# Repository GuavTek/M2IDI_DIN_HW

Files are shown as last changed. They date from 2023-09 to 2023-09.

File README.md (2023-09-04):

This eurorack module is a gateway between MIDI 1.0 over a 5-pin DIN cable, and MIDI 2.0 over the internal bus.
View this project on [CADLAB.io](https://cadlab.io/project/25234) to see renders of schematics and PCBs, as well as current issues. 

<h2> A part of the M2IDI prototypes </h2>

<p>
The code for this module can be found on  
<a href="https://github.com/GuavTek/M2IDI_DIN">
			  GitHub
		  </a>
</p>

<p> 
More info on the M2IDI system can be found on the 
<a href="https://hackaday.io/project/182092-modular-midi">
			  Hackaday project page
		  </a>

</p>

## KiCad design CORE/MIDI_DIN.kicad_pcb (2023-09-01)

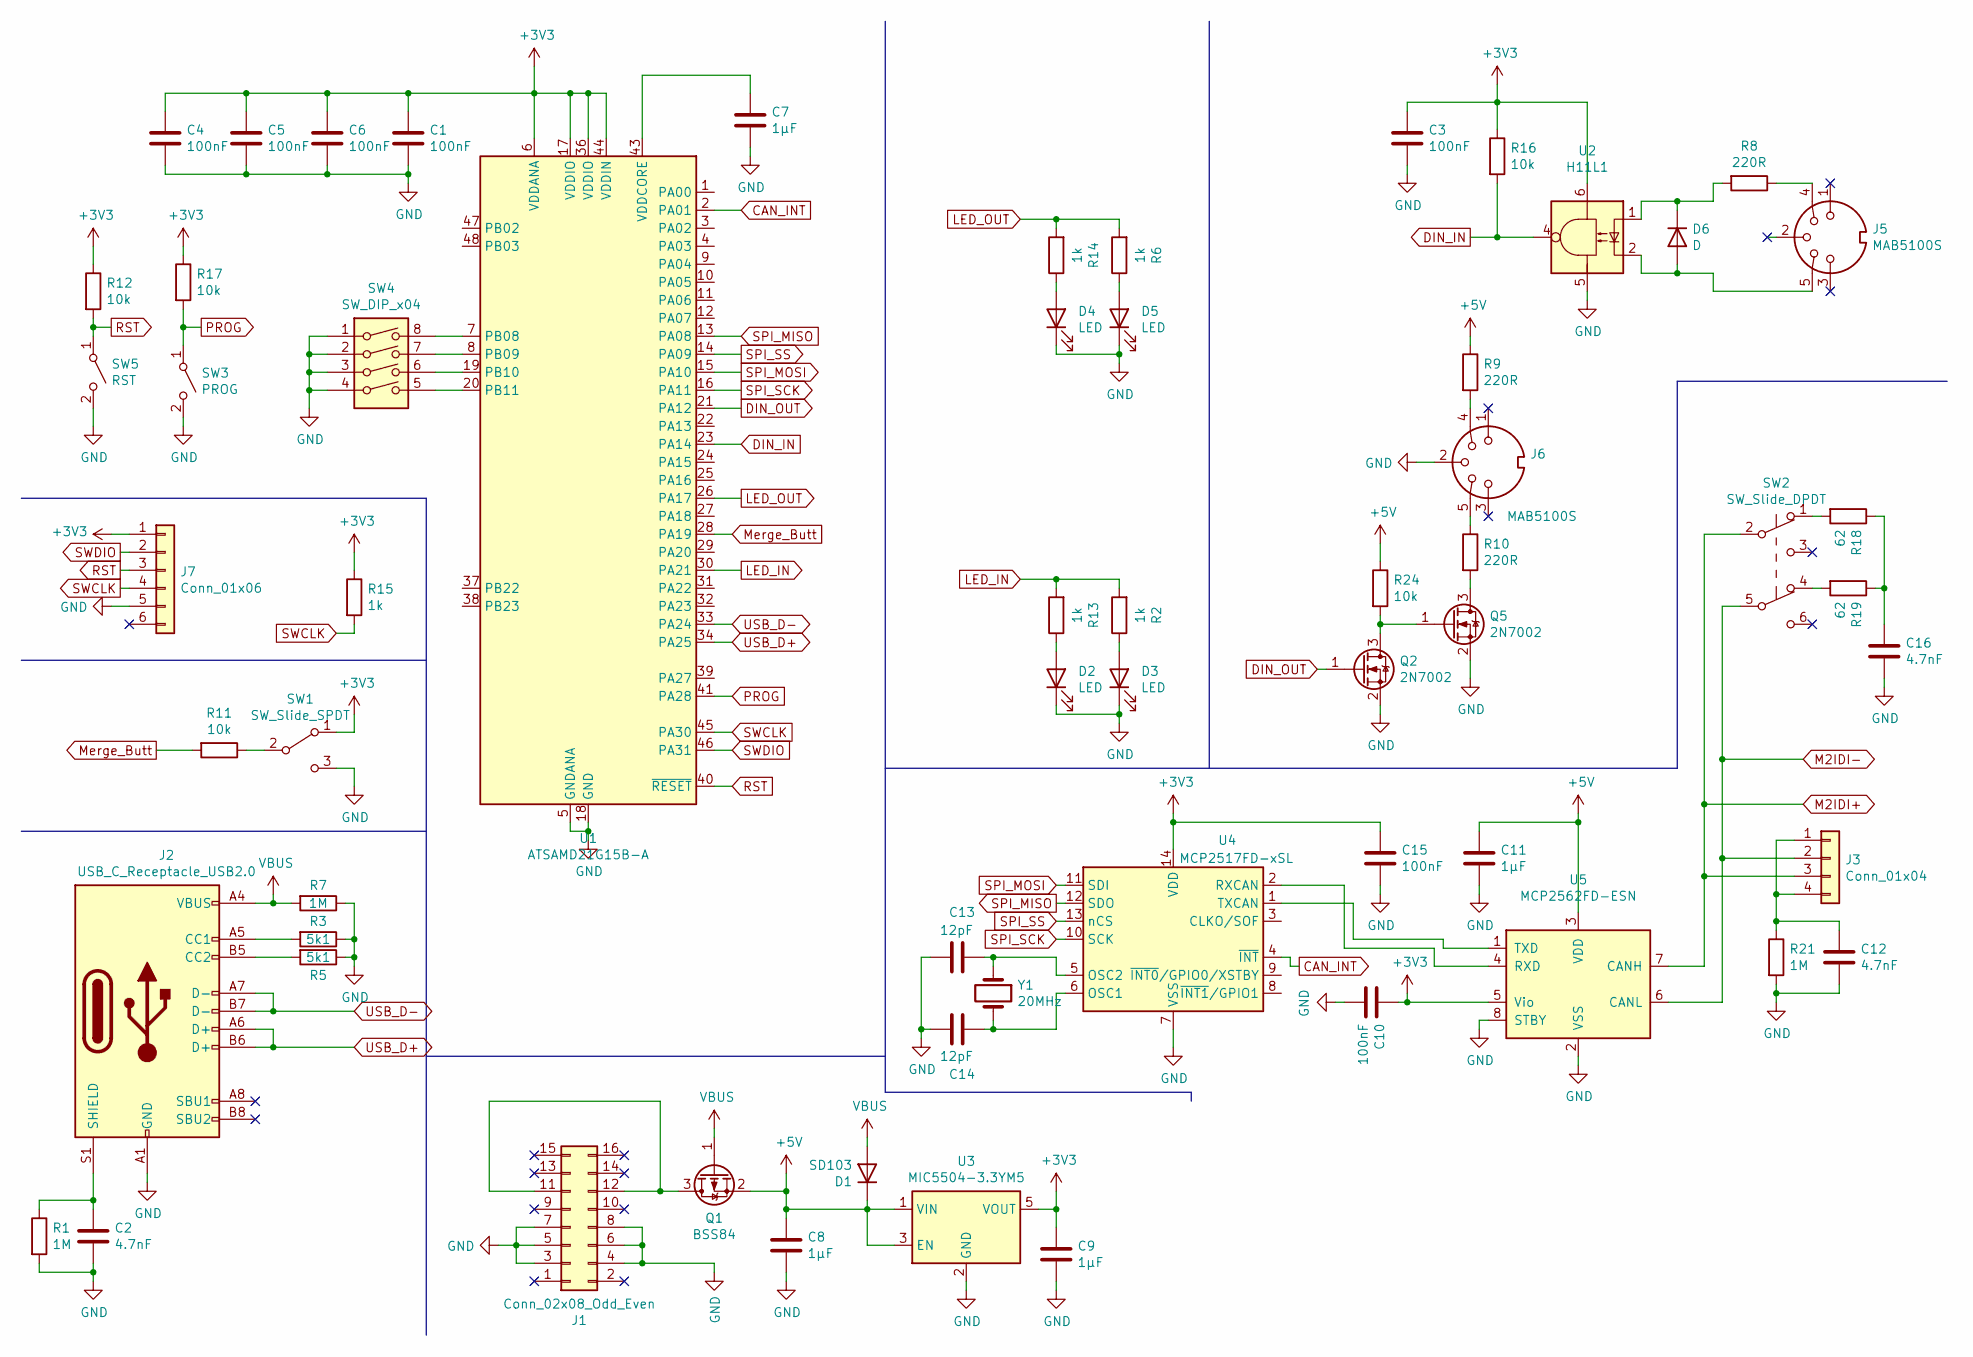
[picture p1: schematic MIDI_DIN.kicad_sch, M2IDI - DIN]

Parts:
C1, C3, C4, C5, C6, C10, C15: 100nF; C_0603_1608Metric
C2, C12, C16: 4.7nF; C_0603_1608Metric
C7, C8, C9, C11: 1µF; C_0603_1608Metric
C13, C14: 12pF; C_0603_1608Metric
D1: SD103; D_SOD-323_HandSoldering
D2, D3, D4, D5: LED; LED_D3.0mm
D6: D; D_SOD-323_HandSoldering
J1: Conn_02x08_Odd_Even; Header_2x8_Shrouded_SMD
J2: USB_C_Receptacle_USB2.0; USB_C_Receptacle_HRO_TYPE-C-31-M-12
J3: Conn_01x04; MicroMatch_04_Vertical_SMD_Lock
J5, J6: MAB5100S; DIN-5_Hirschmann
J7: Conn_01x06; TSM103-DH
Q1: BSS84; SOT-23
Q2, Q5: 2N7002; SOT-23
R1, R7, R21: 1M; R_0603_1608Metric
R2, R6, R13, R14, R15: 1k; R_0603_1608Metric
R3, R5: 5k1; R_0603_1608Metric
R8, R9, R10: 220R; R_0603_1608Metric
R11, R12, R16, R17, R24: 10k; R_0603_1608Metric
R18, R19: 62; R_0805_2012Metric
SW1: SW_Slide_SPDT; SlideSwitch-SS12D10
SW2: SW_Slide_DPDT; SlideDPDT_JS202011
SW3: PROG; Tactile_angled_5x5.4_SMD
SW4: SW_DIP_x04; SW_DIP_SPSTx04_Slide_Copal_CHS-04B_W7.62mm_P1.27mm
SW5: RST; Tactile_angled_5x5.4_SMD
U1: ATSAMD21G15B-A; TQFP-48_7x7mm_P0.5mm
U2: H11L1; DIP-6_W7.62mm_SMDSocket_SmallPads
U3: MIC5504-3.3YM5; SOT-23-5
U4: MCP2517FD-xSL; SOIC-14_3.9x8.7mm_P1.27mm
U5: MCP2562FD-ESN; SOIC-8_3.9x4.9mm_P1.27mm
Y1: 20MHz; Crystal_2pin_2.0x2.5mm

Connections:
+3V3: C1.1, C3.1, C4.1, C5.1, C6.1, C9.1, C10.1, C15.1, J7.1, R12.1, R15.1, R16.1, R17.1, SW1.1 (A), U1.6 (VDDANA), U1.17 (VDDIO), U1.36 (VDDIO), U1.44 (VDDIN), U2.6, U3.5 (VOUT), U4.14 (VDD), U5.5 (Vio)
+5V: C8.1, C11.1, D1.1 (K), Q1.2 (S), R9.1, R24.1, U3.1 (VIN), U3.3 (EN), U5.3 (VDD)
CAN_INT: U1.2 (PA01), U4.4 (~INT)
DIN_IN: R16.2, U1.23 (PA14), U2.4
DIN_OUT: Q2.1 (G), U1.21 (PA12)
GND: C1.2, C2.2, C3.2, C4.2, C5.2, C6.2, C7.2, C8.2, C9.2, C10.2, C11.2, C12.2, C13.2, C14.2, C15.2, C16.2, D2.1 (K), D3.1 (K), D4.1 (K), D5.1 (K), J1.3, J1.4, J1.5, J1.6, J1.7, J1.8, J2.A1 (GND), J2.A12 (GND), J2.B1 (GND), J2.B12 (GND), J6.2, J7.5, Q2.2 (S), Q5.2 (S), R1.2, R3.1, R5.1, R7.1, R21.2, SW1.3 (C), SW3.2 (B), SW4.1, SW4.2, SW4.3, SW4.4, SW5.2 (B), U1.5 (GNDANA), U1.18 (GND), U1.35 (GND), U1.42 (GND), U2.5, U3.2 (GND), U4.7 (VSS), U5.2 (VSS), U5.8 (STBY)
LED_IN: R2.2, R13.2, U1.30 (PA21)
LED_OUT: R6.2, R14.2, U1.26 (PA17)
M2IDI+: J3.3, SW2.2 (B), U5.7 (CANH)
M2IDI-: J3.2, SW2.5 (B), U5.6 (CANL)
Merge_Butt: R11.2, U1.28 (PA19)
unnamed: C16.1, R18.1, R19.1
unnamed: D2.2 (A), R13.1
unnamed: D3.2 (A), R2.1
unnamed: D4.2 (A), R14.1
unnamed: D5.2 (A), R6.1
unnamed: D6.2 (A), J5.5, U2.2
unnamed: D6.1 (K), R8.2, U2.1
unnamed: J1.11, J1.12, Q1.3 (D)
unnamed: J2.A5 (CC1), R3.2
unnamed: J2.B5 (CC2), R5.2
unnamed: C2.1, J2.S1 (SHIELD), R1.1
unnamed: C12.1, J3.1, J3.4, R21.1
unnamed: J5.4, R8.1
unnamed: J6.4, R9.2
unnamed: J6.5, R10.1
unnamed: Q2.3 (D), Q5.1 (G), R24.2
unnamed: Q5.3 (D), R10.2
unnamed: R18.2, SW2.1 (A)
unnamed: R19.2, SW2.4 (A)
unnamed: R11.1, SW1.2 (B)
unnamed: SW4.8, U1.7 (PB08)
unnamed: SW4.7, U1.8 (PB09)
unnamed: SW4.6, U1.19 (PB10)
unnamed: SW4.5, U1.20 (PB11)
unnamed: C7.1, U1.43 (VDDCORE)
unnamed: C14.1, U4.6 (OSC1), Y1.2
unnamed: C13.1, U4.5 (OSC2), Y1.1
unnamed: U4.2 (RXCAN), U5.4 (RXD)
unnamed: U4.1 (TXCAN), U5.1 (TXD)
PROG: R17.2, SW3.1 (A), U1.41 (PA28)
RST: J7.3, R12.2, SW5.1 (A), U1.40 (~RESET)
SPI_MISO: U1.13 (PA08), U4.12 (SDO)
SPI_MOSI: U1.15 (PA10), U4.11 (SDI)
SPI_SCK: U1.16 (PA11), U4.10 (SCK)
SPI_SS: U1.14 (PA09), U4.13 (nCS)
SWCLK: J7.4, R15.2, U1.45 (PA30)
SWDIO: J7.2, U1.46 (PA31)
USB_D+: J2.A6 (D+), J2.B6 (D+), U1.34 (PA25)
USB_D-: J2.A7 (D-), J2.B7 (D-), U1.33 (PA24)
VBUS: D1.2 (A), J2.A4 (VBUS), J2.A9 (VBUS), J2.B4 (VBUS), J2.B9 (VBUS), Q1.1 (G), R7.2

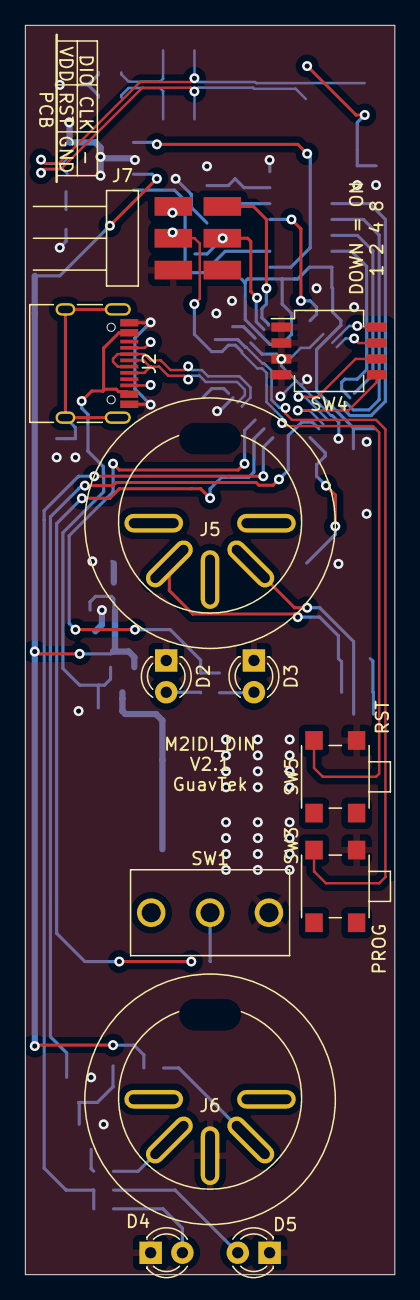
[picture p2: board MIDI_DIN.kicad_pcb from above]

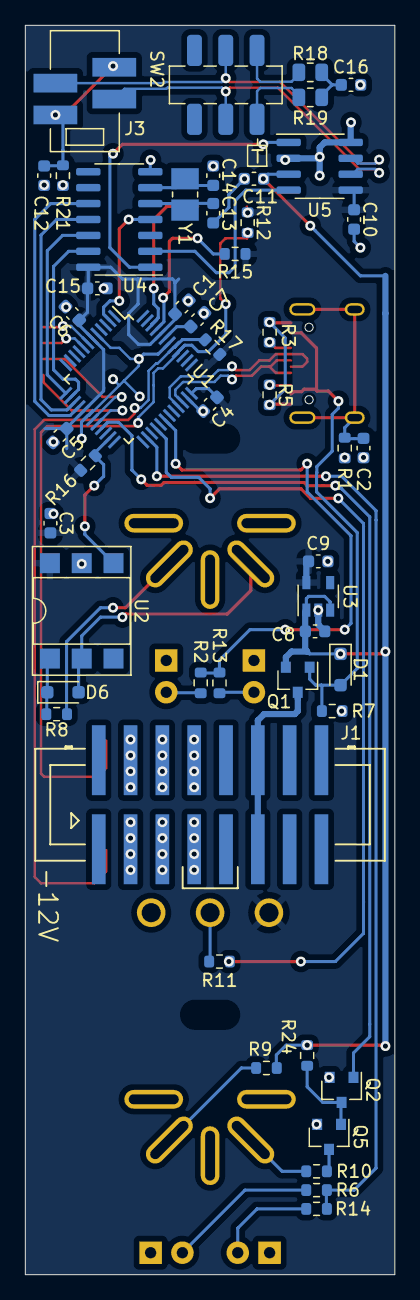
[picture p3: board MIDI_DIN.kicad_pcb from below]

Board: 2 copper layers, 29.5 x 99.8 mm, 62 parts (50 on the bottom side), 51 nets.

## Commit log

2022-02-17 Update termination values
    [MIDI_DIN.sch]
2022-02-17 Fix DRC errors
    [MIDI_DIN.kicad_pcb]
2022-02-19 Add custom symbols and footprints
    [MIDI_DIN.kicad_pcb, MIDI_DIN.sch, MIDI_DIN_front.kicad_pcb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]
2022-12-31 Update PCB
    Fixed stuff
    [MIDI_DIN.kicad_pcb, MIDI_DIN.sch]
2022-12-31 Add horizontal prog header
    [MIDI_DIN.kicad_pcb, MIDI_DIN.sch]
2022-12-31 Make round slot corners
    [MIDI_DIN_front.kicad_pcb]
2023-03-17 Minor adjustments
    [MIDI_DIN.kicad_pcb, MIDI_DIN.sch]
2023-03-17 Update sheet metadata
    [MIDI_DIN.kicad_pcb, MIDI_DIN.sch]
2023-03-17 Update module name
    [MIDI_DIN_front.kicad_pcb]
2023-03-17 Move resistor out of the way
    [MIDI_DIN.kicad_pcb]
2023-03-18 Make room for latching connector
    [MIDI_DIN.kicad_pcb, MIDI_DIN.sch]
2023-03-19 Add 5V power protection
    Prevent USB connection from powering other modules
    [MIDI_DIN.kicad_pcb, MIDI_DIN.sch]
2023-03-19 Add pulldown for USB power protection
    [MIDI_DIN.kicad_pcb, MIDI_DIN.sch]
2023-04-04 Rearrange and re-wire
    [MIDI_DIN.kicad_pcb, MIDI_DIN.sch]
2023-04-08 Update front panel
    [MIDI_DIN_front.kicad_pcb, MIDI_DIN_front.kicad_sch, MIDI_DIN_front.sch]
2023-04-09 Switch to KiCAD 7
    [MIDI_DIN.kicad_pcb, MIDI_DIN.kicad_sch, MIDI_DIN.sch]
2023-04-09 Fix new DRC
    [MIDI_DIN.kicad_pcb]
2023-04-09 Ignore DRC warnings
    [MIDI_DIN.kicad_pcb]
2023-07-09 Change CAN tranceiver to MCP2562
    [MIDI_DIN.kicad_pcb, MIDI_DIN.kicad_sch]
2023-07-09 Fix 2x8 header footprint
    [MIDI_DIN.kicad_pcb]
2023-07-09 Fix crystal footprint
    [MIDI_DIN.kicad_pcb]
2023-07-09 Fix DRC warnings
    [MIDI_DIN.kicad_pcb]
2023-09-01 Finalize module
    [MIDI_DIN.kicad_pcb, MIDI_DIN.kicad_sch, MIDI_DIN_front.kicad_pcb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]
2023-09-16 Add warning about bootloader
    [MIDI_DIN.kicad_sch]
2024-03-31 Switch from CC license to CERN open hardware
